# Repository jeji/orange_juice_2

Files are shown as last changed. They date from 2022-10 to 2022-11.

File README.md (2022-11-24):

# 我的频道 My Channel 
youtube: https://www.youtube.com/channel/UChTFW-Y9eg54AaTY_yama7A \
bilibili：https://b23.tv/pqzW2up

# 版本信息 Release Note
2022/11/12: v0.8_zero2 Remix from [orange juice for orange pi zero](https://github.com/jeji/orange_juice) based on v0.8 \

**[香橙派Zero版本](https://github.com/jeji/orange_juice)** \
**[Version for Orange Pi Zero](https://github.com/jeji/orange_juice)**

# 信息 Information
- 本项目是在[香橙派Zero版本](https://github.com/jeji/orange_juice)基础上为**香橙派zero2**设计的klipper扩展板
- 除**板子尺寸及GPIO配置与[香橙派Zero版本](https://github.com/jeji/orange_juice_2)有所区别**外，其他信息例如BOM等都与[香橙派Zero版本](https://github.com/jeji/orange_juice)一致
- **(!)请确保你认真[香橙派Zero版本](https://github.com/jeji/orange_juice)说明文档**
- gerber文件夹下为嘉立创EDA导出文件，可直接领券下单 

- This project is based on [Orange Pi Zero version](https://github.com/jeji/orange_juice)
- Except **GPIO config and board size**, Other inform is same as [orange juice for orange pi zero](https://github.com/jeji/orange_juice)
- **(!)Make sure you read [orange juice for orange pi zero](https://github.com/jeji/orange_juice) carefully**
- The zip file under "gerber" folder is exported from EasyEDA, it can be used to place order on JLC directly

# 软件 Software
**(!) 以下配置依赖香橙派已经被正确配置成klipper客户端，并且香橙派配置名为"opi"** \
具体方法请参考 https://www.klipper3d.org/RPi_microcontroller.html \
**(!) Following configuration is assuming that your pi has been config as a klipper client already with name "opi"** \
If not, please refer to  https://www.klipper3d.org/RPi_microcontroller.html 

ADXL345配置 \
ADXL345 configuration 

```
[adxl345]
cs_pin: opi:gpio233
spi_bus: spidev1.0

[resonance_tester]
accel_chip: adxl345
probe_points: 60,60,20 #测试点，需要更改为你机器热床中心点，依次为x,y,z
```

MAX31865配置如下，**(!) 你还需要在本节或者其他文件里定义挤出机其他配置** \
MAX31865 config, **(!) you have to define other extruder value seperately** 

```
[extruder]
sensor_type: MAX31865
sensor_pin: opi:gpio1
spi_software_sclk_pin: opi:gpio70
spi_software_mosi_pin: opi:gpio69
spi_software_miso_pin: opi:gpio72
rtd_nominal_r: 100
rtd_reference_r: 430
rtd_num_of_wires: 2
rtd_use_50Hz_filter: True
```

PWM接口配置 \
PWM Port configuration

下为PWM控制的输出插座，对应插槽PWM1 ~ PWM3 \
**(!) 请注意，由于香橙派内核原因，PWM2和PWM3从系统加电启动到klipper正式运行前，默认为高电平，即为打开状态。待klipper正式运行后恢复设置状态** \
PWM control input-voltage output slot \
**(!) Pay attention, because of the linux kernel complied by Orange Pi, the PMW2 and PWM3 is on HIGH (ON) from the power on till klipper start functioning**
```
[fan_generic PWM1_Fan]
pin: opi:gpio74
max_power: 1
shutdown_speed: 0
cycle_time: 0.01
#hardware_pwm:
kick_start_time: 0.5
off_below: 0.1
#enable_pin:
#   See the "fan" section for a description of the above parameters.

[fan_generic PWM2_Fan]
pin: opi:gpio78
max_power: 1
shutdown_speed: 0
cycle_time: 0.01
#hardware_pwm:
kick_start_time: 0.5
off_below: 0.1
#enable_pin:
#   See the "fan" section for a description of the above parameters.

[fan_generic PWM3_Fan]
pin: opi:gpio79
max_power: 1
shutdown_speed: 0
cycle_time: 0.01
#hardware_pwm:
kick_start_time: 0.5
off_below: 0.1
#enable_pin:
#   See the "fan" section for a description of the above parameters.
```

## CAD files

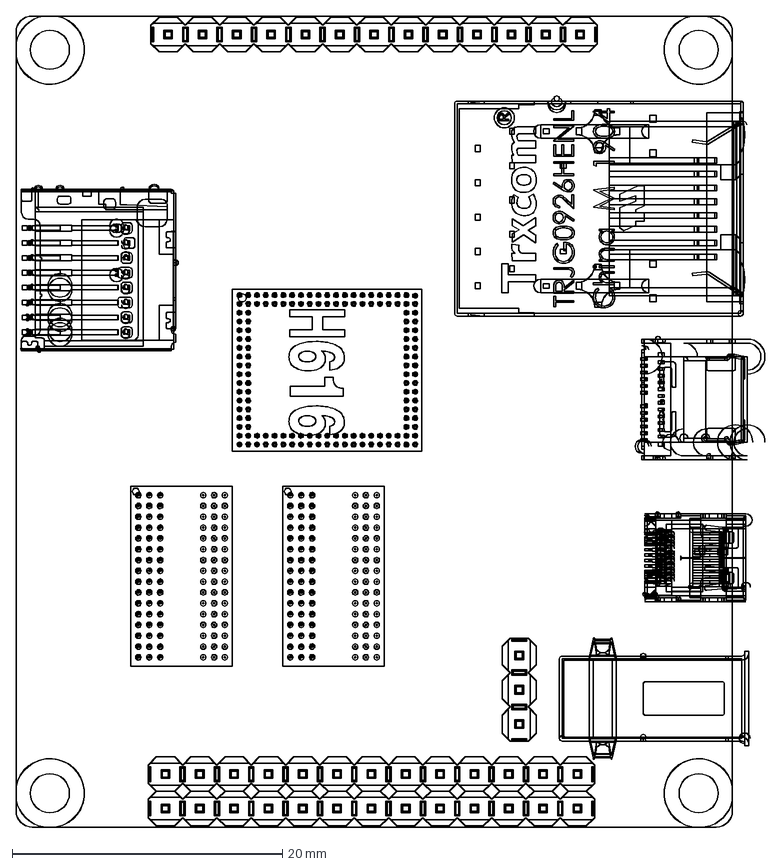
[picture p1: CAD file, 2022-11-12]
cad/OrangePi_Zero2 Top Down.dxf
55.4 x 60.0 mm

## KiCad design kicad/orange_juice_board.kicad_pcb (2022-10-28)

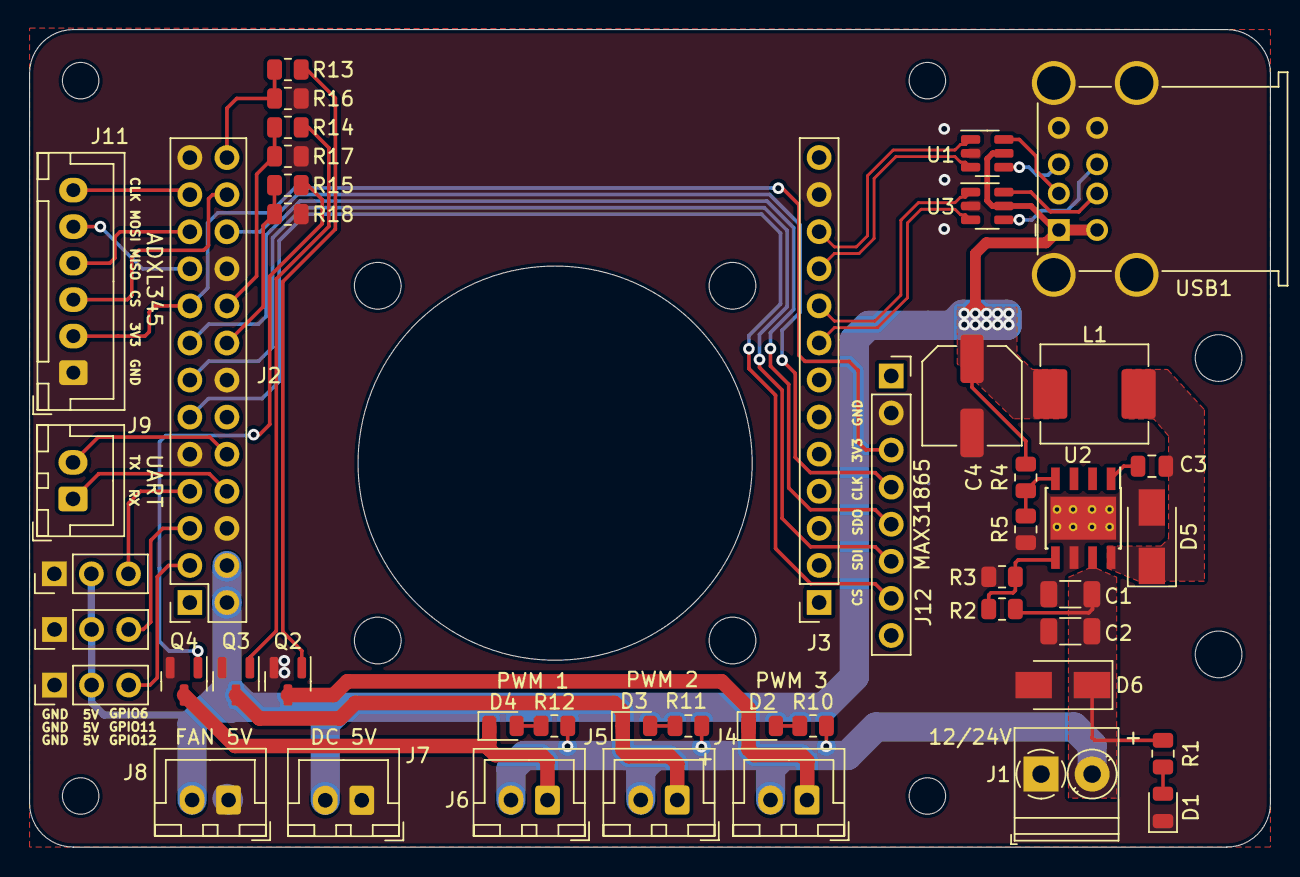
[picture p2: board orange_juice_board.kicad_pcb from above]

Board: 2 copper layers, 85.0 x 56.0 mm, 52 parts (0 on the bottom side), 42 nets.

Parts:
C1, C2: 10uF; C_1206_3216Metric
C3: 10nF; C_0805_2012Metric
C4: 220uF; C_Elec_6.3x5.4
D2: PWM1_STATUS; LED_0805_2012Metric
D3, D3#2: PWM2_STATUS; LED_0805_2012Metric
D4: PWM3_STATUS; LED_0805_2012Metric
D5: B340A; D_SMA
D6: SMAJ24A; D_SMA
H5, H6, H7, H8: MH_FAN; MountingHole_3.2mm_M3
H9, H10: MH_MAX31865; MountingHole_3.2mm_M3
J2: DC_INPUT; TerminalBlock_Phoenix_PT-1,5-2-3.5-H_1x02_P3.50mm_Horizontal
J3: CONN_ADXL345; JST_XH_B6B-XH-A_1x06_P2.50mm_Vertical
J4: OrangePi Zero GPIO PINs; PinSocket_2x13_P2.54mm_Vertical
J7: OrangePi Zero Function Interface; PinSocket_1x13_P2.54mm_Vertical
J8: FAN_5v; JST_XH_B2B-XH-A_1x02_P2.50mm_Vertical
J9: PWR_5v; JST_XH_B2B-XH-A_1x02_P2.50mm_Vertical
J10: GPIO12_Head; PinHeader_1x03_P2.54mm_Vertical
J10#2: PWM_OUT1; JST_XH_B2B-XH-A_1x02_P2.50mm_Vertical
J11: CONN_UART; JST_XH_B2B-XH-A_1x02_P2.50mm_Vertical
J12: PWM_OUT2; JST_XH_B2B-XH-A_1x02_P2.50mm_Vertical
J12#2: Conn_01x08; PinSocket_1x08_P2.54mm_Vertical
J13: GPIO6_Head; PinHeader_1x03_P2.54mm_Vertical
J14: GPIO11_Head; PinHeader_1x03_P2.54mm_Vertical
J15: PWM_OUT3; JST_XH_B2B-XH-A_1x02_P2.50mm_Vertical
L1: 22uH; L_Abracon_ASPI-0630LR
Q2, Q3, Q4: AO3400A; SOT-23
R2: 100K; R_0805_2012Metric
R3: 25K5; R_0805_2012Metric
R4: 10K; R_0805_2012Metric
R4#2, R7, R7#2, R10: 4k7; R_0805_2012Metric
R5, R8, R14: 100; R_0805_2012Metric
R5#2: 3.24K; R_0805_2012Metric
R6, R9, R15: 10k; R_0805_2012Metric
U1, U3: USBLC6-2SC6; SOT-23-6
U2: TPS5430DDA; TI_SO-PowerPAD-8_ThermalVias
USB1: USB_A_Port_x2; USB_A_Wuerth_61400826021_Horizontal_Stacked

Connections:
BUCK_BOOT: C3.2, U2.1 (BOOT)
BUCK_EN: R2.2, R3.1, U2.5 (EN)
BUCK_IN: C1.1, C2.1, D6.1 (A1), J2.2, J10#2.2, J12.2, J15.2, R2.1, R4#2.2, R7.1, R7#2.2, R10.2, U2.7 (VIN)
BUCK_OUT: C4.1, J4.2, J4.4, J8.2, J9.2, J10.2, J13.2, J14.2, L1.2, R4.1, U1.5 (VBUS), U3.5 (VBUS), USB1.1 (VCC), USB1.5 (VCC)
BUCK_PH: C3.1, D5.1 (K), L1.1, U2.8 (PH)
BUCK_VSNS: R4.2, R5#2.1, U2.4 (VSENSE)
GND: C1.2, C2.2, C4.2, D3#2.1 (K), D5.2 (A), D6.2 (A2), J2.1, J3.1, J4.6, J4.9, J4.14, J4.20, J4.25, J7.12, J8.1, J9.1, J10.1, J12#2.2, J13.1, J14.1, Q2.2 (S), Q3.2 (S), Q4.2 (S), R3.2, R5#2.2, R6.1, R9.1, R15.1, U1.2 (GND), U2.6 (GND), U2.9 (GNDPAD), U3.2 (GND), USB1.4 (GND), USB1.8 (GND), USB1.9 (Shield)
GPIO6: J4.7, J13.3
GPIO11: J4.5, J14.3
GPIO12: J4.3, J10.3
GPIO_0_SDI: J4.13, J12#2.6
GPIO_1_CS: J4.11, J12#2.7
GPIO_2_CLK: J4.22, J12#2.4
GPIO_3_SDO: J4.15, J12#2.5
GPIO_10: J4.26, R5.2, R6.2
GPIO_18: J4.18, R8.2, R9.2
GPIO_19: J4.16, R14.2, R15.2
unnamed: D3#2.2 (A), R7.2
unnamed: D2.1 (K), J10#2.1, Q2.3 (D)
unnamed: D2.2 (A), R4#2.1
unnamed: D3.1 (K), J12.1, Q3.3 (D)
unnamed: D3.2 (A), R7#2.1
unnamed: D4.1 (K), J15.1, Q4.3 (D)
unnamed: D4.2 (A), R10.1
unnamed: Q2.1 (G), R5.1
unnamed: Q3.1 (G), R8.1
unnamed: Q4.1 (G), R14.1
PI_3.3V: J3.2, J4.17, J12#2.3
SPI1_CLK: J3.6, J4.23
SPI1_CS: J3.3, J4.24
SPI1_MISO: J3.4, J4.21
SPI1_MOSI: J3.5, J4.19
UART1_RX: J4.10, J11.2
UART1_TX: J4.8, J11.1
USB2_Conn_D+: U1.4 (I/O2), USB1.3 (D+)
USB2_Conn_D-: U1.6 (I/O1), USB1.2 (D-)
USB2_D+: J7.10, U1.3 (I/O2)
USB2_D-: J7.11, U1.1 (I/O1)
USB3_Conn_D+: U3.4 (I/O2), USB1.7 (D+)
USB3_Conn_D-: U3.6 (I/O1), USB1.6 (D-)
USB3_D+: J7.8, U3.3 (I/O2)
USB3_D-: J7.9, U3.1 (I/O1)

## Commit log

2022-10-28 Init submit
    Initial submit with kicad based on orange juice v0.8
    [orange_juice_board.kicad_pcb, orange_juice_board.kicad_sch]
2022-10-31 some progress
    [orange_juice_board.kicad_sch]
2022-11-12 v0.8 bate version
    [OrangePi_Zero2 Top Down.dxf, orange_juice_board.kicad_sch]
